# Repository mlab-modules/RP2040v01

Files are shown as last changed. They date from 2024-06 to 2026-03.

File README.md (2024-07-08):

# RP2040v01 - RP2040 Processor Module
## Introduction

The [MLAB](https://www.mlab.cz/) module RP2040v01 featuring the [RP2040](https://www.raspberrypi.com/documentation/microcontrollers/rp2040.html) processor is a powerful and flexible development board designed for a wide range of applications. The [RP2040](https://www.raspberrypi.com/documentation/microcontrollers/rp2040.html), a microcontroller from the Raspberry Pi Foundation, offers dual Arm Cortex-M0+ cores and extensive peripheral support.

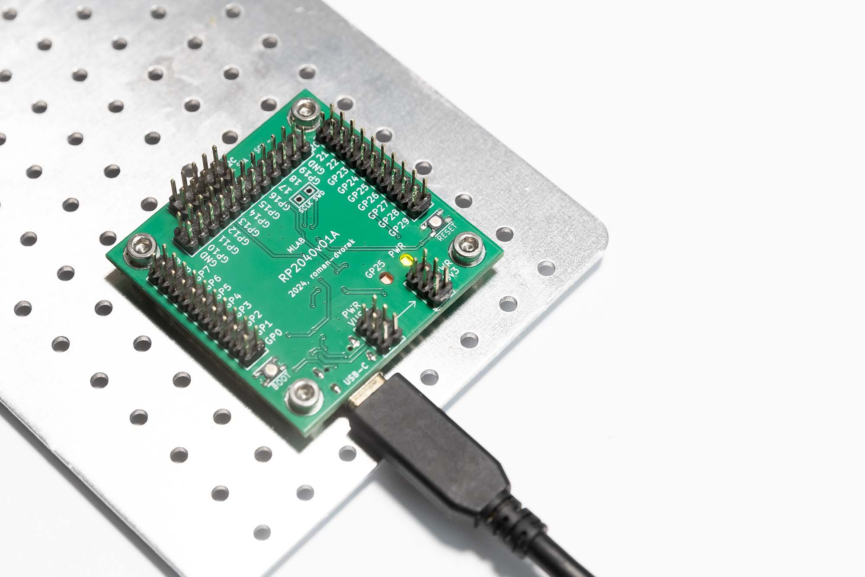
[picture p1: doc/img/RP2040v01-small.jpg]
RP2040v01 Image


## Features

- **Processor**: Dual-core Arm Cortex-M0+ [RP2040](https://www.raspberrypi.com/documentation/microcontrollers/rp2040.html).
- **Buttons**: Boot and Reset buttons for easy programming and reset.
- **GPIO**: Processor pins are exposed on doubleheader pins for flexible connectivity, as is usual in MLAB modules.
- **LED**: An LED connected via a transistor on pin 25 for status indication.
- **USB**: USB-C connector for power and data communication.
- **Power Management**: Integrated power converter to step down from 5V to 3.3V.

## Processor Details

The RP2040 processor, developed by the Raspberry Pi Foundation, is a versatile microcontroller that includes the following key features:

- **Architecture**: Dual-core Arm Cortex-M0+.
- **Clock Speed**: Up to 133 MHz.
- **Memory**: 264KB of SRAM, and support for up to 16MB of external QSPI flash memory.
- **GPIO**: 30 GPIO pins, including a rich set of I/O options like UART, SPI, I2C, PWM, and ADC.
- **Timers**: Multiple timers and a real-time clock (RTC).
- **DMA**: Direct Memory Access controller for efficient data transfer.
- **Debugging**: SWD (Serial Wire Debug) interface for debugging and development.

## Module Schematic

The schematic of the RP2040v01 module illustrates the connections and components used in the design. This includes the layout of the RP2040 processor, power management circuitry, and GPIO pin headers.



If you would like more details, please consult the example codes and used ICs documentation.

## Programming Options

The RP2040 microcontroller offers multiple programming options, providing flexibility for various types of developers:

1. **MicroPython**:
   - An easy-to-use Python interpreter ideal for beginners.
   - Allows rapid prototyping and development with an extensive set of libraries.
   - [Official documentation](https://datasheets.raspberrypi.com/pico/raspberry-pi-pico-python-sdk.pdf)

2. **C/C++ with the Pico SDK**:
   - Provides low-level access to the hardware for maximum performance.
   - Suitable for more complex projects and experienced developers.
   - Requires setting up the Pico SDK and toolchain on your development environment.
   - [User-friendly documentation](https://datasheets.raspberrypi.com/pico/raspberry-pi-pico-c-sdk.pdf)

3. **Arduino IDE**:
   - Offers a familiar environment for those used to Arduino development.
   - Supports both the Mbed OS core and the C/C++ SDK-based core.
   - Simplifies the process of writing, compiling, and uploading sketches to the RP2040.
   - [Documentation](https://github.com/earlephilhower/arduino-pico)

### Drag-and-Drop Programming:
   - Allows you to upload firmware by simply dragging and dropping a UF2 file.
   - Useful for quick updates and easy deployment without needing an IDE.
   - Minimal knowledge required, best for beginners.

## Usage

1. **Flashing Firmware**:
   - Hold the Boot button and press the Reset button.
   - Release the Reset button while holding the Boot button to enter bootloader mode.
   - Drag and drop the firmware file onto the USB drive that appears.

2. **Programming**:
   - Select the appropriate board and port and use your preferred IDE (e.g., Thonny, VS Code, Arduino IDE).
   - Write your code and upload it to the RP2040.

## References
 - [RP2040 documentation page](https://www.raspberrypi.com/documentation/microcontrollers/rp2040.html)

## Examples

Example code and projects can be found in the `examples` directory of the repository. These include basic GPIO manipulation, sensor interfacing, and communication protocols.

## Applications

### Logic analyzer
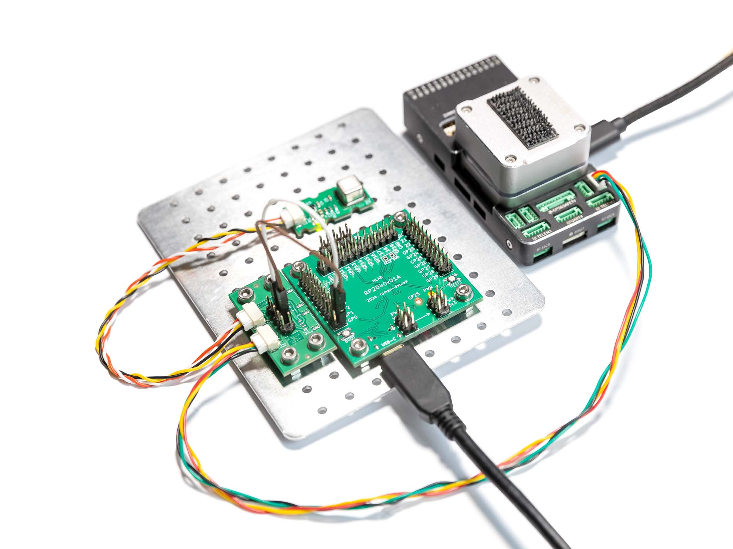
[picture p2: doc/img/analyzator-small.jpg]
RP2040-based MLAB logic analyzer


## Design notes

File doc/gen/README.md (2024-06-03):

# PCB

Board size: 50.29x50.29 mm (1.98x1.98 inches)

- This is the size of the rectangle that contains the board
- Thickness: 1.6 mm (63 mils)
- Material: FR4
- Finish: HAL
- Layers: 2
- Copper thickness: 35 µm

Solder mask: TOP / BOTTOM

- Color: Green

Silk screen: TOP / BOTTOM

- Color: White

# Important sizes

Clearance: 0.2 mm (8 mils)

Track width: 0.2 mm (8 mils)

- By design rules: 0.0 mm (0 mils)

Drill: 0.4 mm (16 mils)

- Vias: 0.4 mm (16 mils) [Design: 0.4 mm (16 mils)]
- Pads: 0.6 mm (24 mils)
- The above values are real drill sizes, they add 0.1 mm (4 mils) to plated holes (PTH)

Via: 0.6/0.3 mm (24/12 mils)

- By design rules: 0.5/0.3 mm (20/12 mils)
- Micro via: yes [0.2/0.1 mm (8/4 mils)]
- Buried/blind via: yes
- Total: 51 (thru: 51 buried/blind: 0 micro: 0)

Outer Annular Ring: 0.1 mm (4 mils)

- By design rules: 0.1 mm (4 mils)

Eurocircuits class: 8C
- Using min drill 0.35 mm for an OAR of 0.1 mm

# General stats

Components count: (SMD/THT)

- Top: 2/7 (SMD + THT)
- Bottom: 33/0 (SMD)

Defined tracks:

- 0.2 mm (8 mils)
- 0.8 mm (31 mils)

Used tracks:

- 0.2 mm (8 mils) (138) defined: yes
- 0.3 mm (12 mils) (218) defined: no
- 0.4 mm (16 mils) (41) defined: no
- 0.5 mm (20 mils) (42) defined: no

Defined vias:

Used vias:

- 0.6/0.3 mm (24/12 mils) (Count: 51, Aspect: 2.7 A) defined: no

Holes (excluding vias):

- 0.5 mm (20 mils) (32)
- 0.65 mm (26 mils) (2)
- 0.89 mm (35 mils) (88)
- 3.2 mm (126 mils) (4)

Oval holes:

- 0.6x1.4 mm (24x55 mils) (2)
- 0.6x1.7 mm (24x67 mils) (2)
- 1.9x2.4 mm (75x94 mils) (2)

Drill tools (including vias and computing adjusts and rounding):

- 0.4 mm (16 mils) (51)
- 0.6 mm (24 mils) (32)
- 0.65 mm (26 mils) (2)
- 0.7 mm (28 mils) (4)
- 1.0 mm (39 mils) (88)
- 1.9 mm (75 mils) (2)
- 3.3 mm (130 mils) (4)

Solder paste stats:

Using a paste with 87.75 % alloy, that has an specific gravity for the alloy of 7.4 g/cm³
and 1.0 g/cm³ for the flux. This paste has an specific gravity of  4.15 g/cm³.

The stencil thickness is  0.12 mm.

| Side | Pads with paste | Area [mm²] | Paste [g] |
|---|---|---|---|
| Top | 8 | 5.46 | 0.03 |
| Bottom | 149 | 133.21 | 0.66 |
| Total  | 157 | 138.67 | 0.69 |

Note: this is just an approximation to the theoretical value. Margins of the solder mask and waste aren't computed.

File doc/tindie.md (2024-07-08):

## RP2040v01 - Powerful Development Module

### What is it?

MLAB RP2040v01 is an MLAB module containing a dual-core ARM RP2040 processor. Thanks to the sophisticated design of the MLAB system and a vast array of additional modules, you can quickly and flexibly create complex devices. It is ideal for experimental, educational, scientific, and industrial applications.

### Why did you make it?

We created the RP2040v01 to provide developers with a robust and flexible platform that simplifies the process of creating and prototyping projects. As part of the MLAB ecosystem, this module can be combined with other MLAB modules to build a wide range of constructions and devices, catering to both beginners and advanced users.

### What makes it special?

- **Dual-Core Processor**: Utilizes the RP2040 microcontroller with dual Arm Cortex-M0+ cores, capable of up to 133 MHz.
- **Comprehensive Connectivity**: Features 30 GPIO pins, including UART, SPI, I2C, PWM, and ADC.
- **User-Friendly Design**: Includes Boot and Reset buttons, an LED indicator, and a USB-C connector for power and data.
- **Flexible Programming**: Supports MicroPython, C/C++, and Arduino IDE for a wide range of development needs.
- **Easy Firmware Updates**: Drag-and-drop UF2 file uploads for quick firmware updates without needing an IDE.
- **MLAB Compatibility**: Integrates seamlessly with other MLAB modules, enabling the creation of complex systems and devices.

### Features

- **Processor**: Dual-core Arm Cortex-M0+ RP2040.
- **Memory**: 264KB SRAM, support for up to 16MB external QSPI flash.
- **GPIO**: 30 pins with diverse I/O options.
- **USB**: USB-C for power and communication.
- **Buttons**: Boot and Reset.
- **LED**: Status LED on pin 25.
- **Power Management**: Integrated 5V to 3.3V converter.

### Technical Specifications

- **Clock Speed**: Up to 133 MHz.
- **Timers**: Multiple timers and RTC.
- **DMA**: Direct Memory Access controller.
- **Debugging**: SWD interface.

### Possible Uses

- Prototyping and development
- Educational projects
- IoT applications
- Sensor interfacing
- Creating complex systems and designs with other MLAB modules

# The package includes:
- RP2040v01A module with pin headers soldered.
- MLAB ALBASE mounting screw mounted in the module

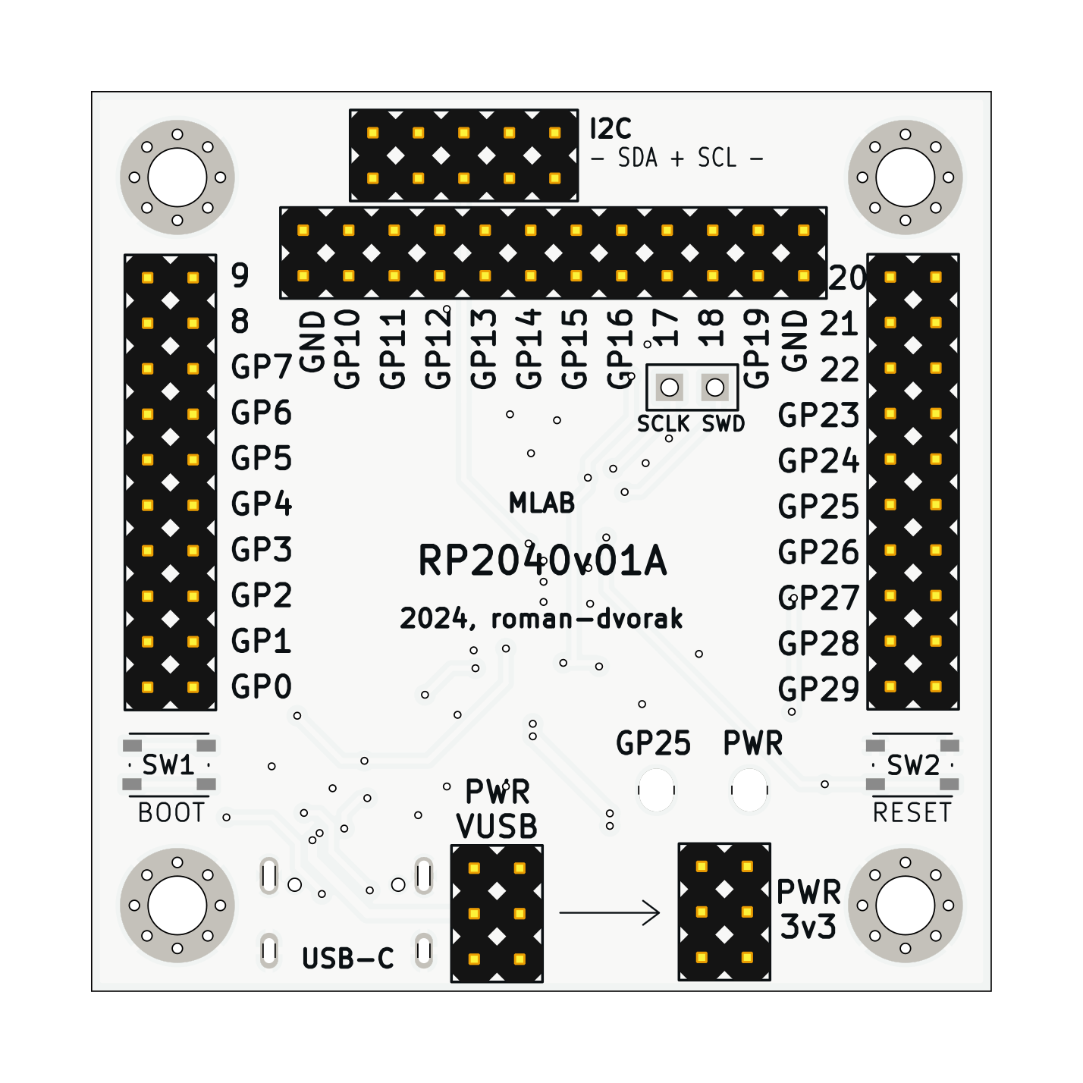
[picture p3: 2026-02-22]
doc/gen/img/RP2040v01-top.png

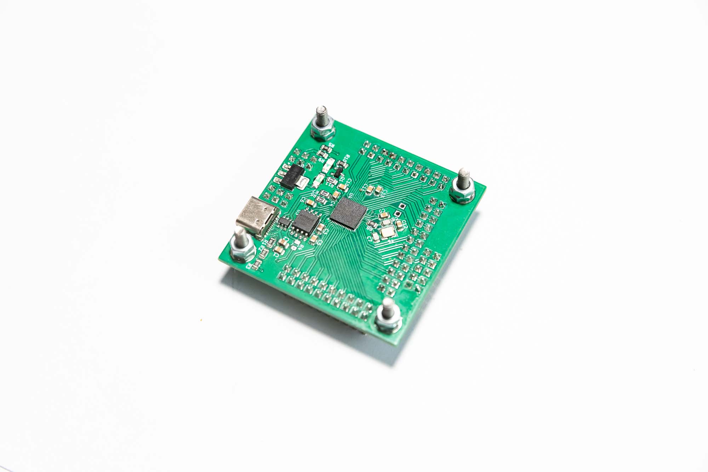
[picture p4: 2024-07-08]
doc/img/RP2040v01_b-small.jpg

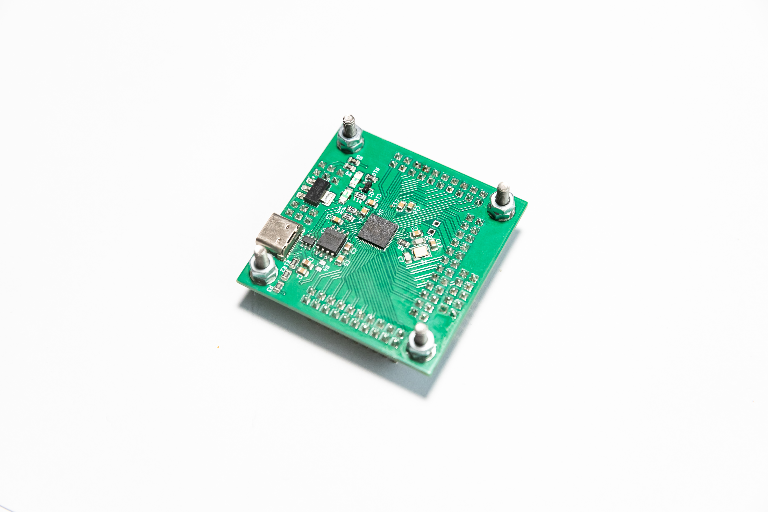
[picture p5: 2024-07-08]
doc/img/RP2040v01_b.jpg

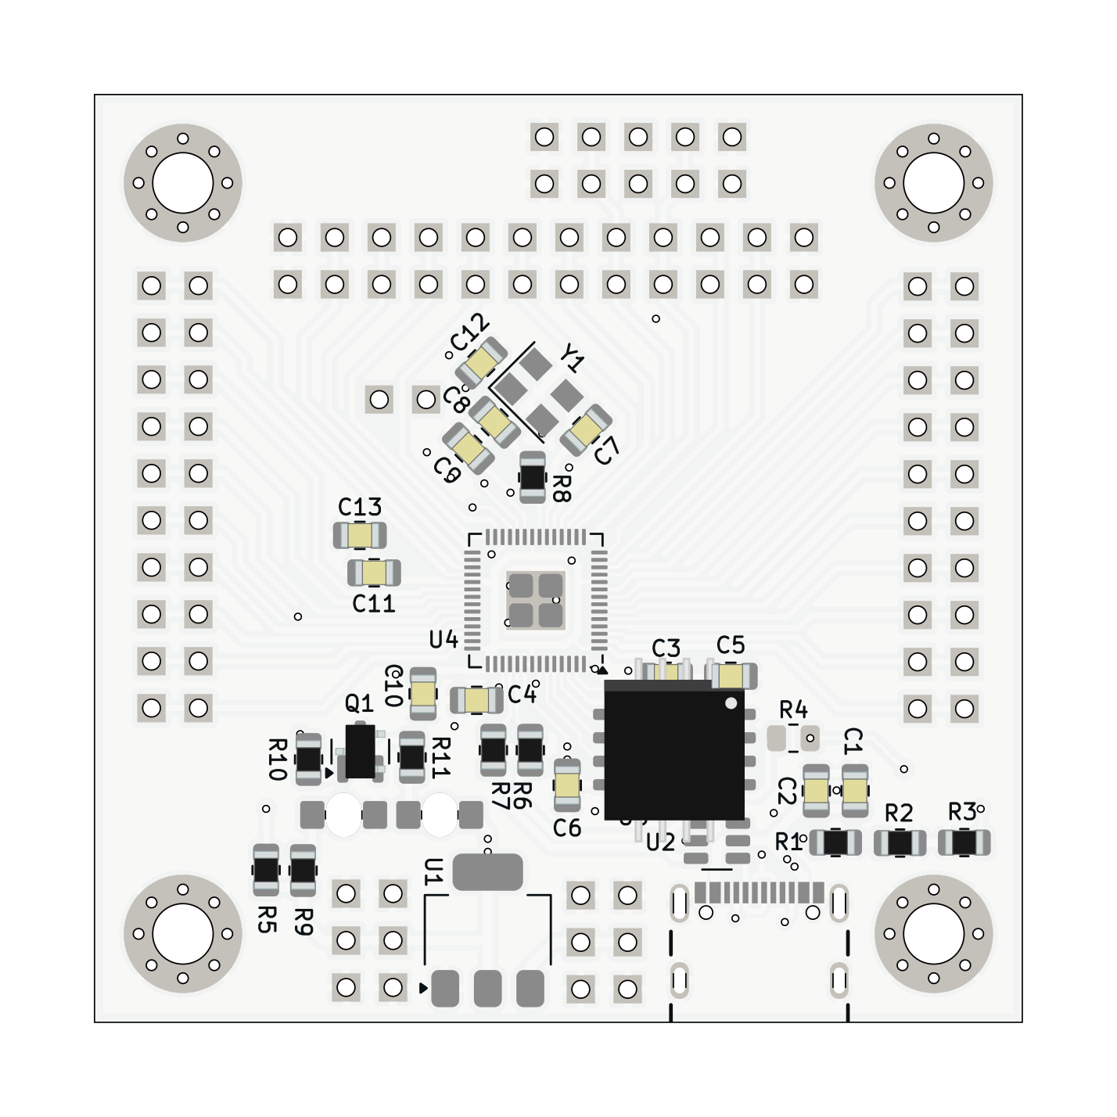
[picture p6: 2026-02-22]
doc/gen/img/RP2040v01-bottom.png

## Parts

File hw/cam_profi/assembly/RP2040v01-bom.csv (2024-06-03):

Component | Description | Part | References | Value | Footprint | Quantity Per PCB | Datasheet | obchod
1 | Unpolarized capacitor, small symbol | C_Small | C7C8 | 27p | C_0805_2012Metric | 2 | ~ | TME
2 | Unpolarized capacitor, small symbol | C_Small | C1C4C5C6C9C10C11 | 100n | C_0805_2012Metric | 7 | ~ | TME
3 | Unpolarized capacitor, small symbol | C_Small | C12C13 | 1u | C_0805_2012Metric | 2 | ~ | TME
4 | Unpolarized capacitor, small symbol | C_Small | C2C3 | 10u | C_0805_2012Metric | 2 | ~ | TME
5 | Light emitting diode, small symbol | LED_Small | D2 | Green | LED_1206_KPTR | 1 | ~ | OK
6 | Light emitting diode, small symbol | LED_Small | D1 | Red | LED_1206_KPTR | 1 | ~ | OK
7 | 2x03 2.54 mm pitch header, 2 pins next to each other are connected | HEADER_2x03_PARALLEL | J1J3 | HEADER_1x03 | Straight_2x03 | 2
8 | 2x10 2.54 mm pitch header, 2 pins next to each other are connected | HEADER_2x10_PARALLEL | J5J6 | HEADER_1x10 | Straight_2x10 | 2
9 | 2x12 2.54 mm pitch header, 2 pins next to each other are connected | HEADER_2x12_PARALLEL | J7 | HEADER_1x10 | Straight_2x12 | 1
10 | 2x05 2.54 mm pitch header, 2 pins next to each other are connected | HEADER_2x05_PARALLEL | J8 | HEADER_2x05 | Straight_2x05 | 1
11 | USB 2.0-only Type-C Receptacle connector | USBC_USB4105-GF-A | J2 | USBC_USB4105-GF-A | USBC GCT_USB4105-GF-A | 1 | https://www.usb.org/sites/default/files/documents/usb_type-c.zip | OK
12 | NPN transistor, base/collector/emitter | Q_NPN_BCE | Q1 | BC817-25 | SOT-23 | 1 | ~ | TME
13 | Resistor, small symbol | R_Small | R6R7 | 27R4 | R_0805_2012Metric | 2 | ~ | TME
14 | Resistor, small symbol | R_Small | R9R10 | 200R | R_0805_2012Metric | 2 | ~ | TME
15 | Resistor, small symbol | R_Small | R11 | 390R | R_0805_2012Metric | 1 | ~
16 | Resistor, small symbol | R_Small | R3R5R8 | 1k | R_0805_2012Metric | 3 | ~ | TME
17 | Resistor, small symbol | R_Small | R1R2 | 5k1 | R_0805_2012Metric | 2 | ~ | TME
18 | Push button switch, generic, two pins | SW_Push | SW1SW2 | 434133025816 | SW_Push_1P1T_NO_Vertical_Wuerth_434133025816 | 2 | ~ | TME
19 | 1A Low drop-out regulator, Fixed Output 3.3V, SOT-223 | NCP1117-3.3_SOT223 | U1 | NCP1117-3.3 | SOT-223-3_TabPin2 | 1 | http://www.onsemi.com/pub_link/Collateral/NCP1117-D.PDF | TME
20 | A microcontroller by Raspberry Pi | RP2040 | U4 | RP2040 | QFN-56-1EP_7x7mm_P0.4mm_EP3.2x3.2mm | 1 | https://datasheets.raspberrypi.com/rp2040/rp2040-datasheet.pdf | Farnell
21 | Very low capacitance ESD protection diode, 2 data-line, SOT-23-6 | USBLC6-2SC6 | U2 | USBLC6-2SC6 | SOT-23-6 | 1 | https://www.st.com/resource/en/datasheet/usblc6-2.pdf | TME
22 | 128Mb Serial Flash Memory, Standard/Dual/Quad SPI, SOIC-8 | W25Q128JVS | U3 | W25Q64JVSSIQ | SOIC-8_5.23x5.23mm_P1.27mm | 1 | http://www.winbond.com/resource-files/w25q128jv_dtr%20revc%2003272018%20plus.pdf | Mouser
23 | Four pin crystal, GND on pins 2 and 4 | Crystal_GND24 | Y1 | LFXTAL082069 | Crystal_SMD_SeikoEpson_FA238V-4Pin_3.2x2.5mm | 1 | ~ | Farnell

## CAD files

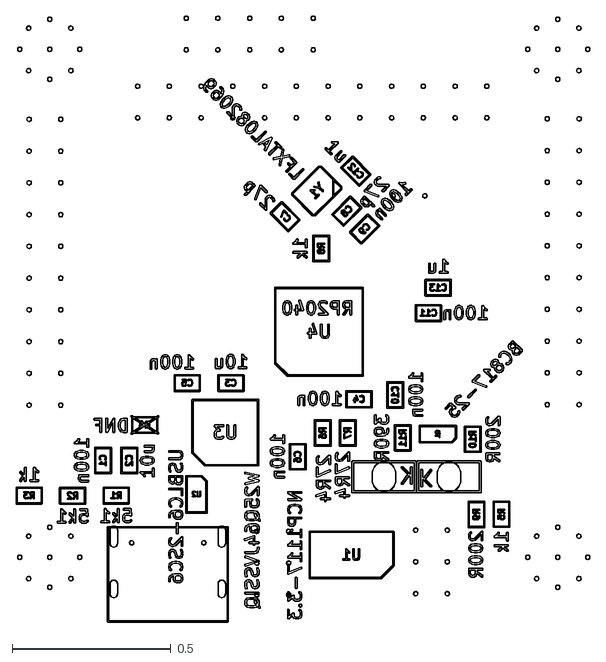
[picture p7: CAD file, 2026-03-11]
doc/gen/dxf/RP2040v01-B_Fab.dxf
1.81 x 1.91

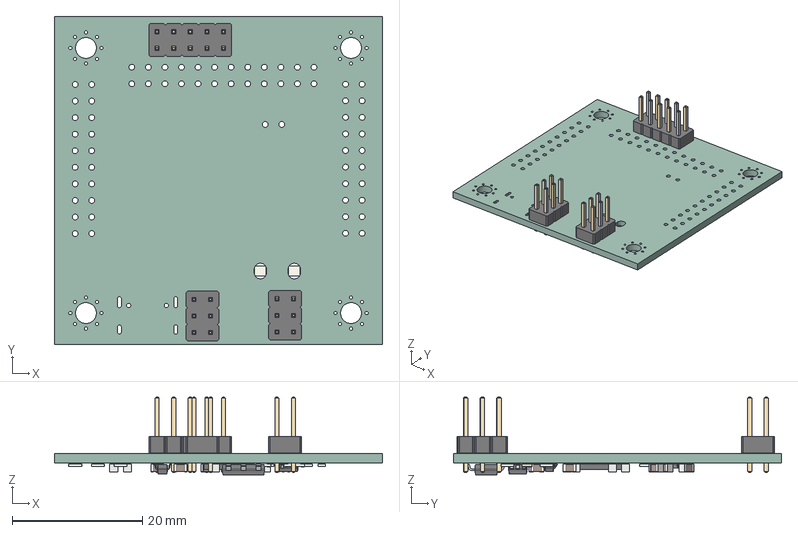
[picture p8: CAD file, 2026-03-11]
doc/gen/RP2040v01.step
50.3 x 50.3 x 11.9 mm
PinHeader_2x03_P2.54mm_Vertical x 2
PinHeader_2x05_P2.54mm_Vertical
C_0805_2012Metric x 13
SOT-223
SOT-23
QFN-56-1EP_7x7mm_P0.4mm_EP3.2x3.2mm
Crystal_SMD_SeikoEpson_FA238V-4Pin_3.2x2.5mm
R_0805_2012Metric x 10
LED_1206_3216Metric x 2
SOT-23-6
kibot_x3ycq2mz_PCB

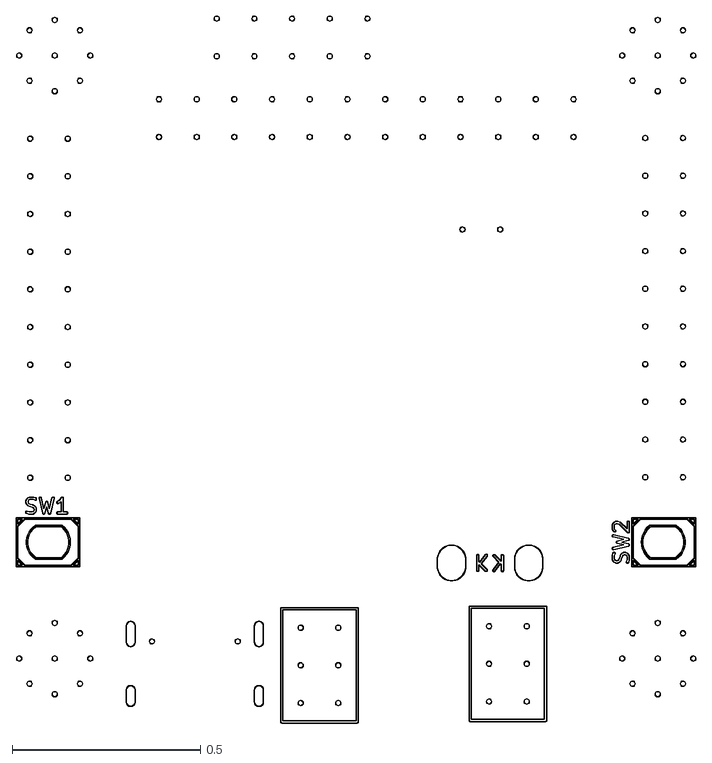
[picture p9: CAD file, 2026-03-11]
doc/gen/dxf/RP2040v01-F_Fab.dxf
1.80 x 1.88

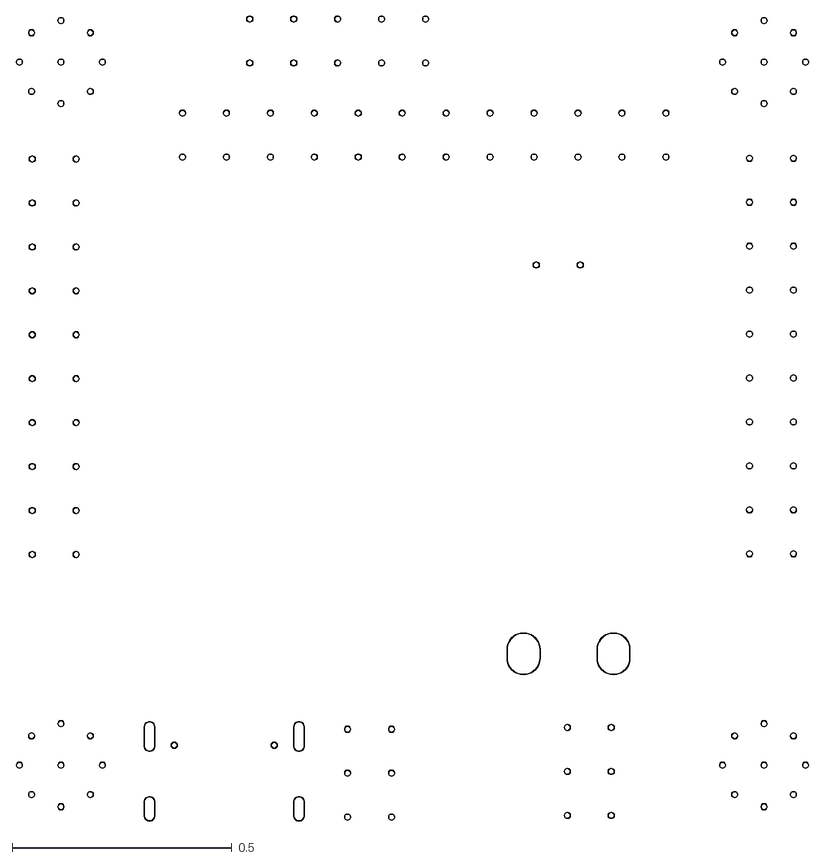
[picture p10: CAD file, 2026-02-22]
doc/gen/dxf/RP2040v01-User_3.dxf
1.80 x 1.83

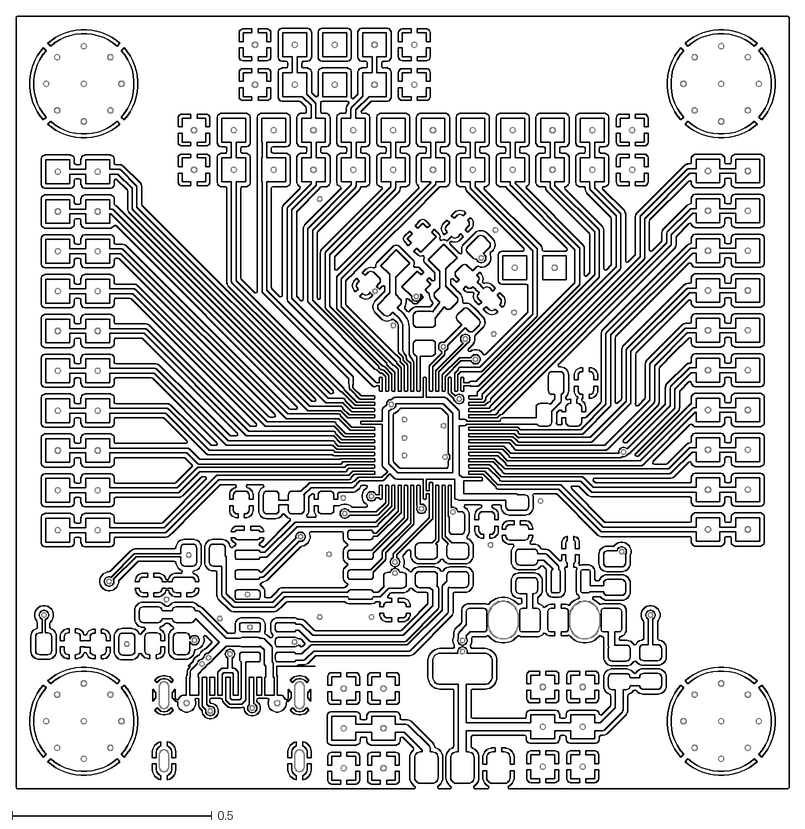
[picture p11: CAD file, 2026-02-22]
doc/gen/dxf/RP2040v01-B_Cu.dxf
1.94 x 1.94

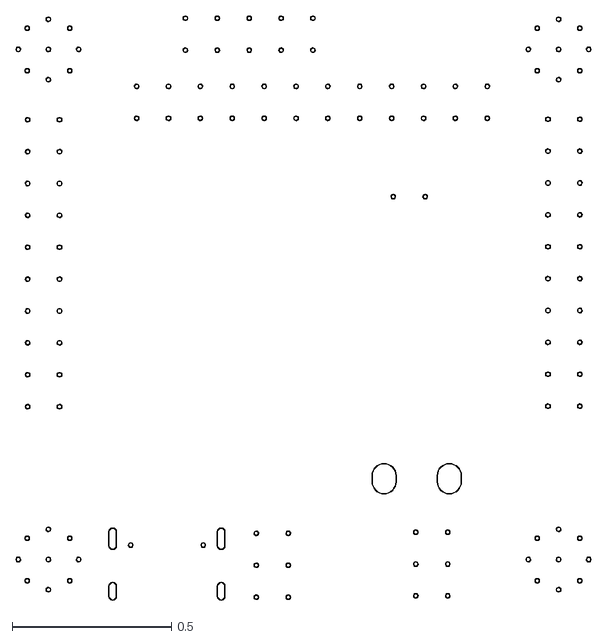
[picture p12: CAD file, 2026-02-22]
doc/gen/dxf/RP2040v01-B_Adhesive.dxf
1.80 x 1.83

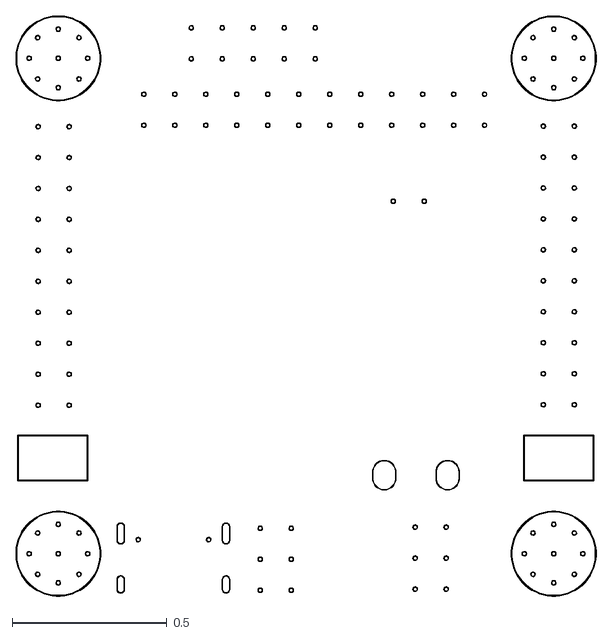
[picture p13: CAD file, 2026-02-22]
doc/gen/dxf/RP2040v01-F_Courtyard.dxf
1.87 x 1.87

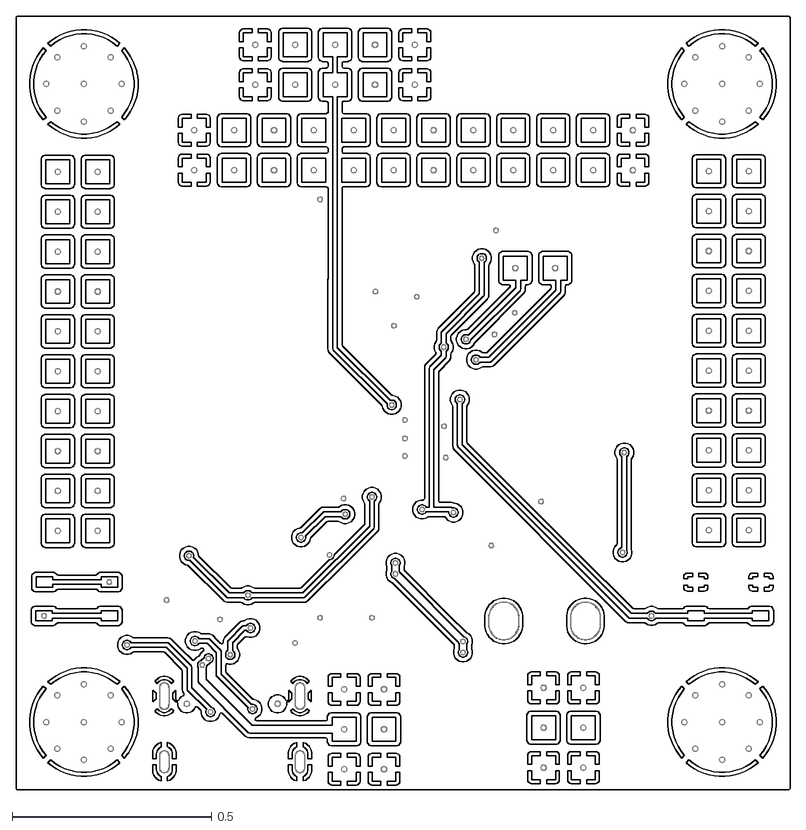
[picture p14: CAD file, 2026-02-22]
doc/gen/dxf/RP2040v01-F_Cu.dxf
1.94 x 1.94

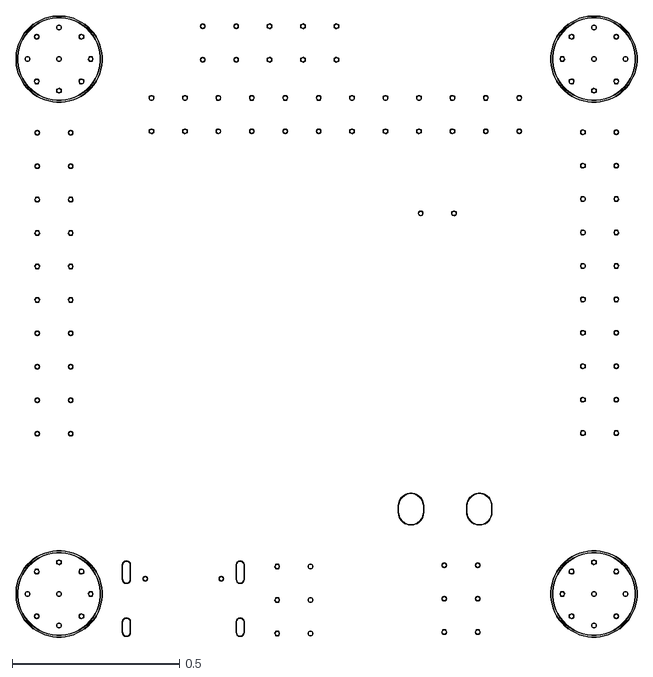
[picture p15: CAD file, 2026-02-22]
doc/gen/dxf/RP2040v01-User_Comments.dxf
1.86 x 1.86

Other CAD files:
doc/gen/dxf/RP2040v01-B_Courtyard.dxf
doc/gen/dxf/RP2040v01-B_Mask.dxf
doc/gen/dxf/RP2040v01-B_Paste.dxf
doc/gen/dxf/RP2040v01-B_Silkscreen.dxf
doc/gen/dxf/RP2040v01-Edge_Cuts.dxf
doc/gen/dxf/RP2040v01-F_Mask.dxf
doc/gen/dxf/RP2040v01-F_Paste.dxf
doc/gen/dxf/RP2040v01-F_Silkscreen.dxf

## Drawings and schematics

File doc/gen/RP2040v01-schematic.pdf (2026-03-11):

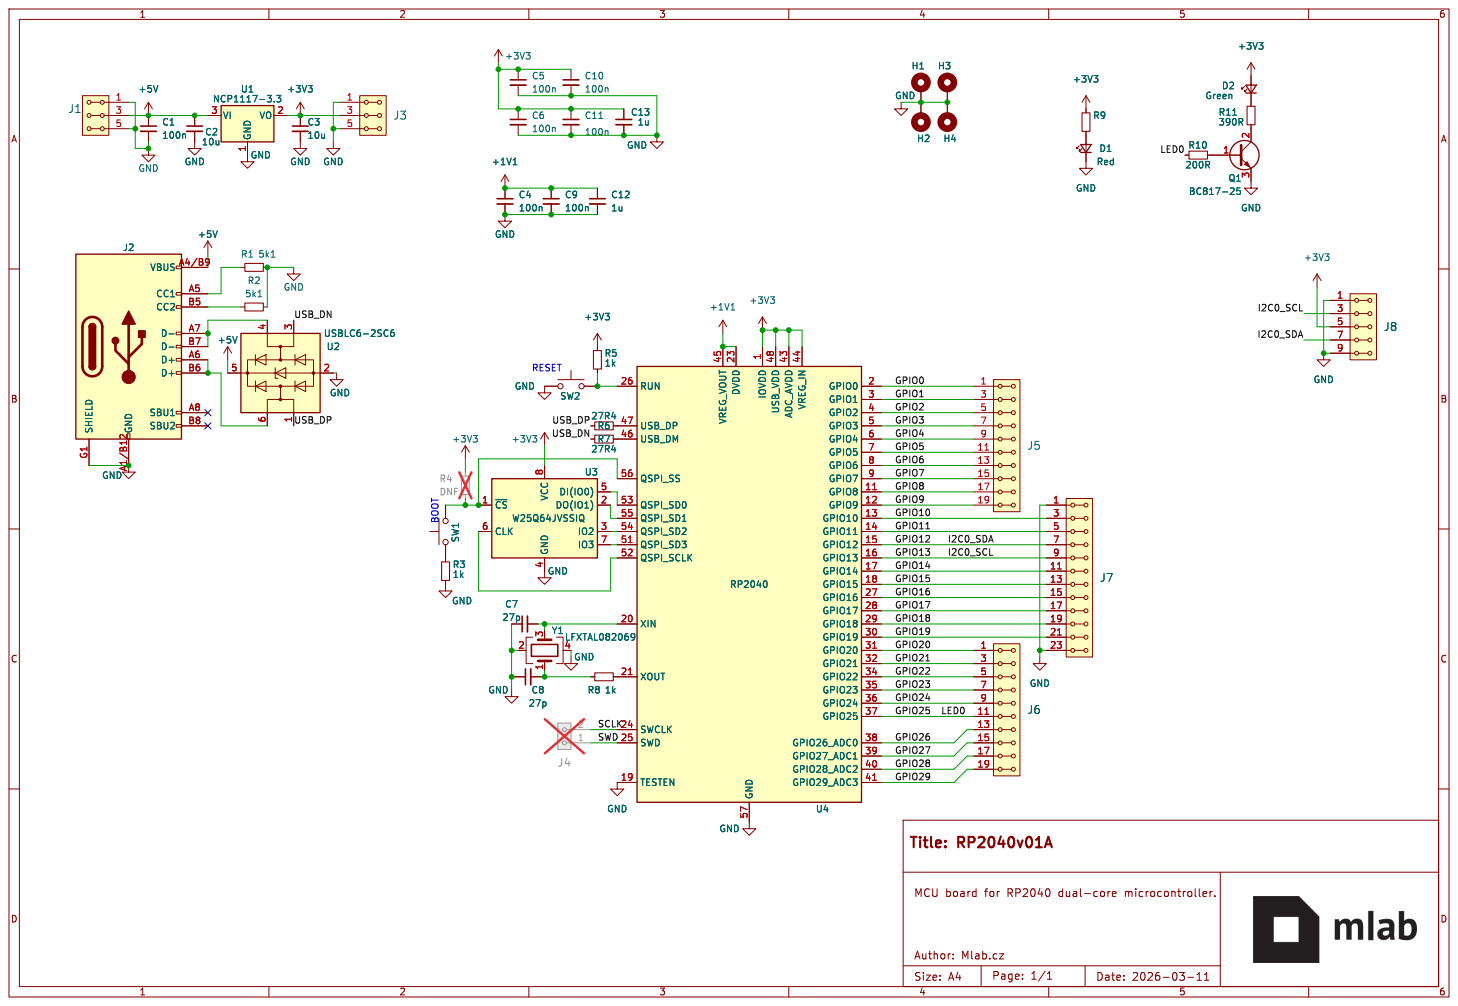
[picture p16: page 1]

3 U2 USBLC6-2SC6 +5V GND SHIELD G1 GND A1/B12 VBUS A4/B9 CC1 A5 CC2 B5 D- A7 D- B7 D+ A6 D+ B6 SBU1 A8 SBU2 B8

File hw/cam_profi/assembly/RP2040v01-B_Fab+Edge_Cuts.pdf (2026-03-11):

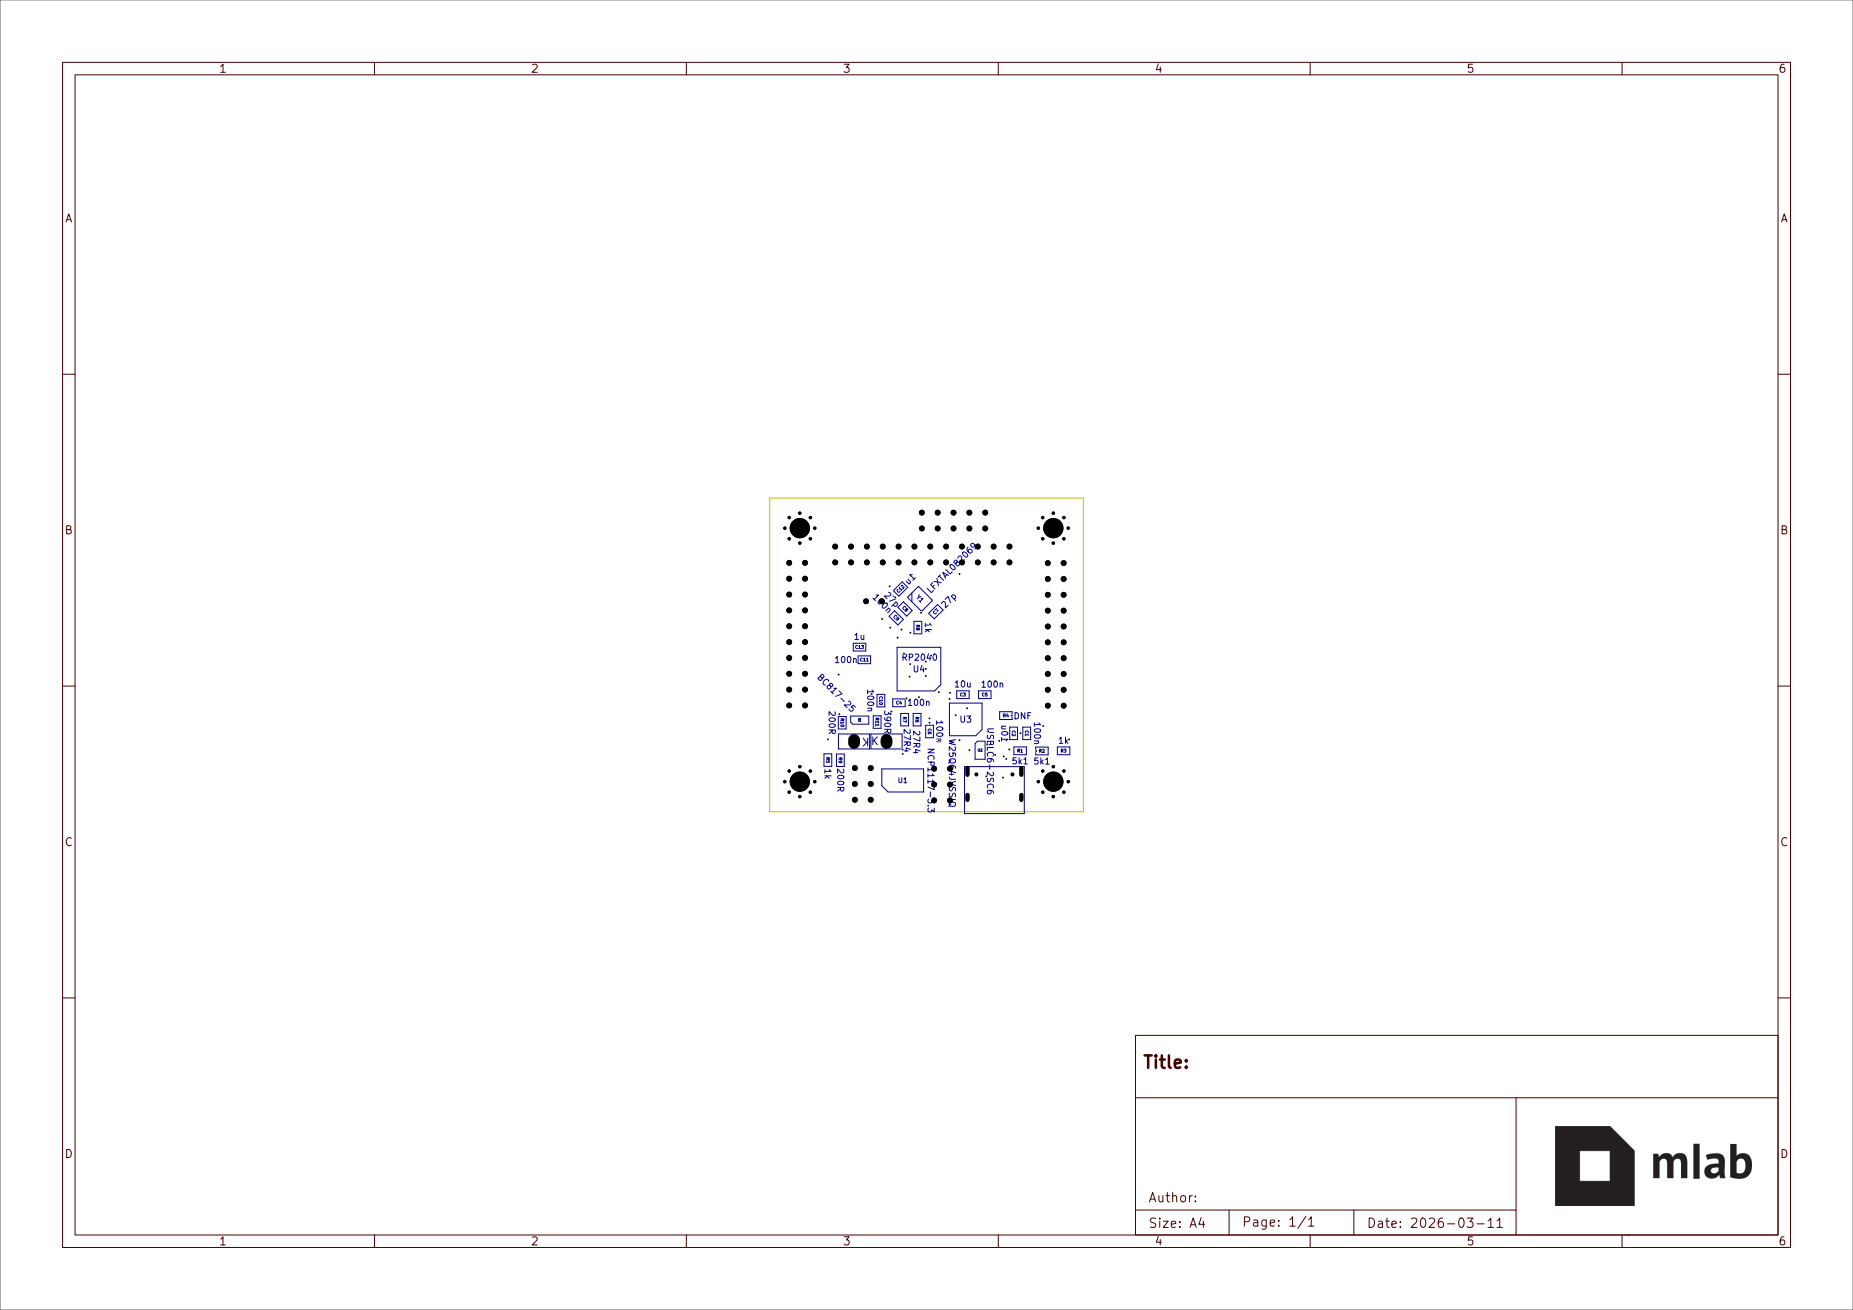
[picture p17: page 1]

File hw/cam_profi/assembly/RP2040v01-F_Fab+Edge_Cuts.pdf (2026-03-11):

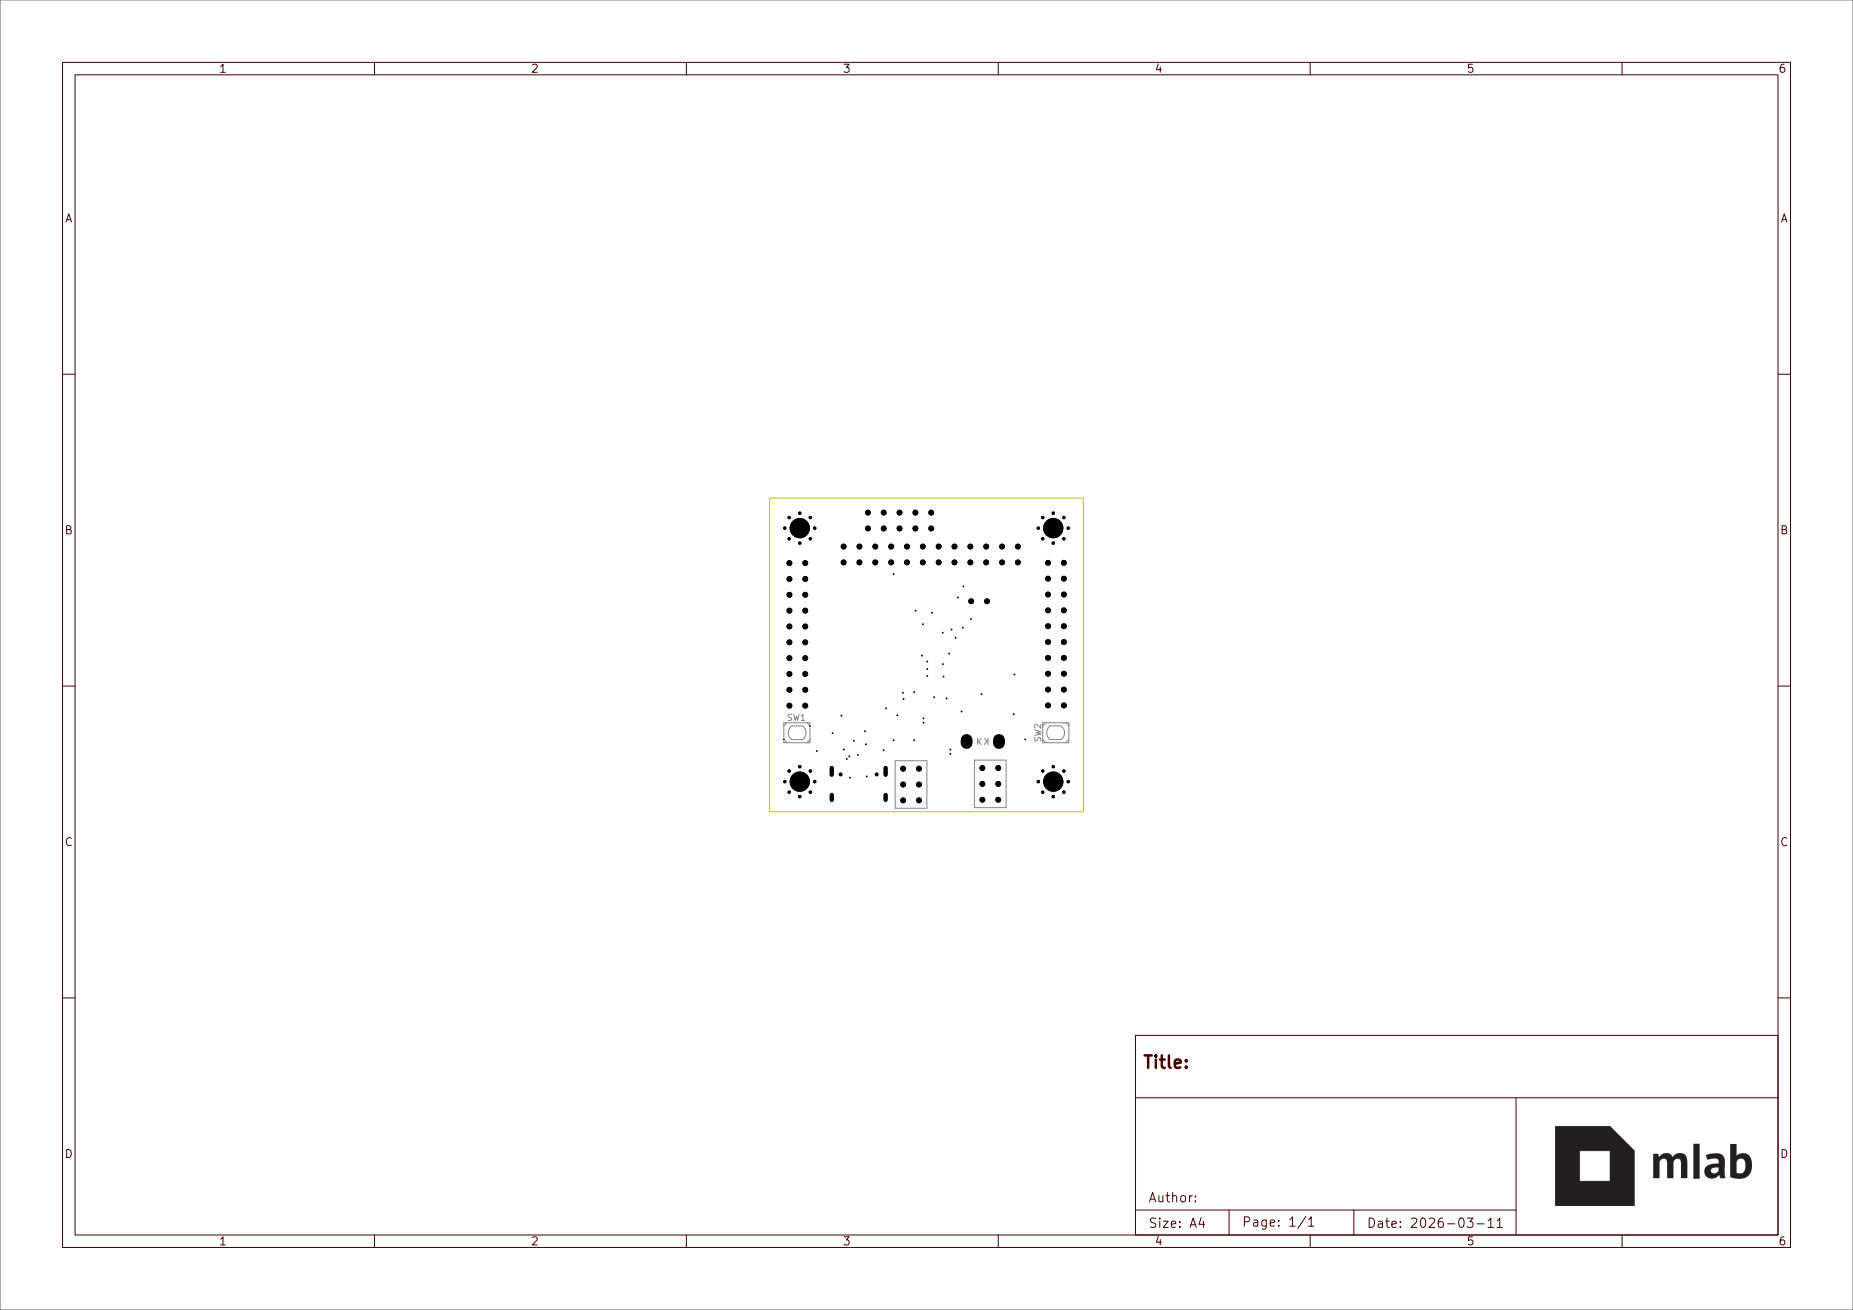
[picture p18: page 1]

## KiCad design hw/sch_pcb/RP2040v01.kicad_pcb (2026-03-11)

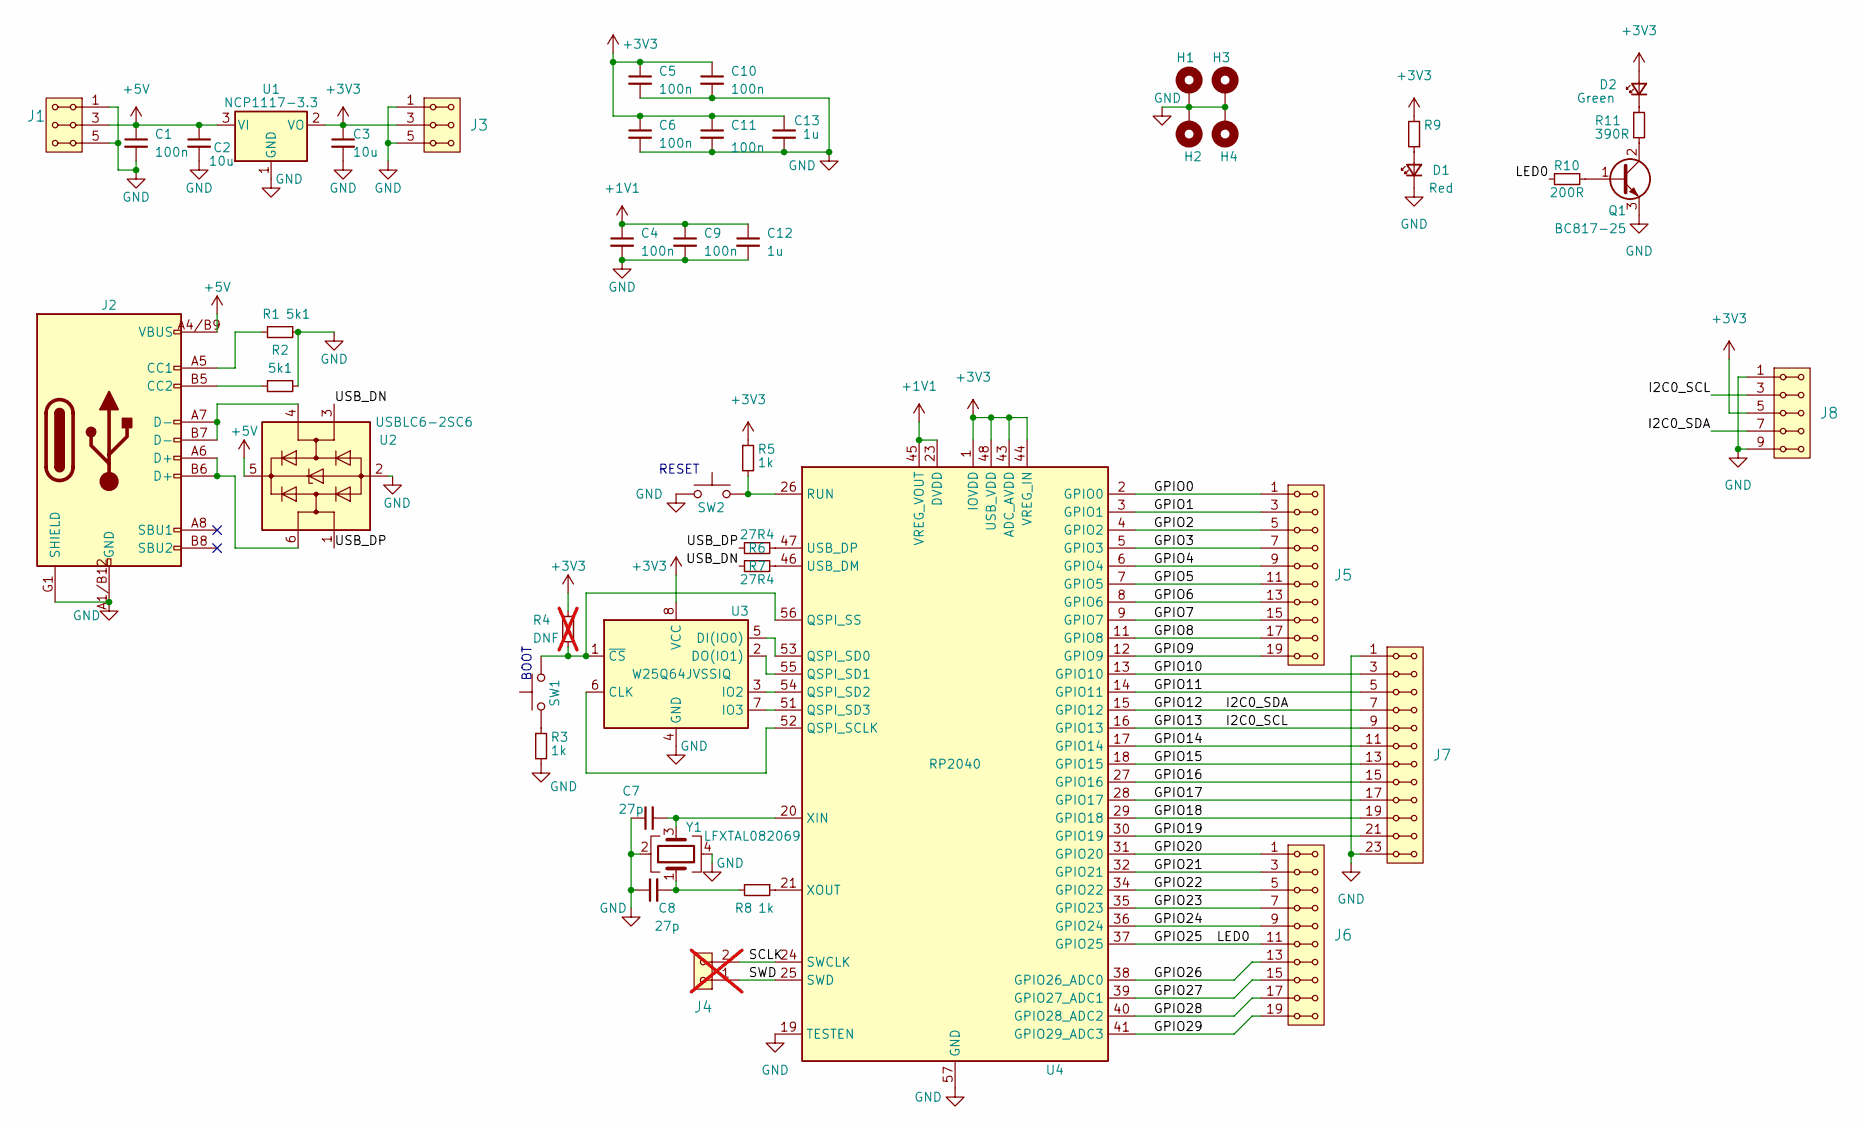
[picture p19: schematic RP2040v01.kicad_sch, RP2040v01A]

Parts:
C1, C4, C5, C6, C9, C10, C11: 100n; C_0805_2012Metric
C2, C3: 10u; C_0805_2012Metric
C7, C8: 27p; C_0805_2012Metric
C12, C13: 1u; C_0805_2012Metric
D1: Red; LED_1206_KPTR
D2: Green; LED_1206_KPTR
H1, H2, H3, H4: MountingHole_Pad; MountingHole_3.2mm_M3_Pad_Via
J1, J3: HEADER_1x03; Straight_2x03
J2: USBC_USB4105-GF-A; USBC GCT_USB4105-GF-A
J4: HEADER_1x10; Straight_1x02; not fitted
J5, J6: HEADER_1x10; Straight_2x10
J7: HEADER_1x10; Straight_2x12
J8: HEADER_2x05; Straight_2x05
Q1: BC817-25; SOT-23
R1, R2: 5k1; R_0805_2012Metric
R3, R5, R8: 1k; R_0805_2012Metric
R4: DNF; R_0805_2012Metric; not fitted
R6, R7: 27R4; R_0805_2012Metric
R9, R10: 200R; R_0805_2012Metric
R11: 390R; R_0805_2012Metric
SW1, SW2: 434133025816; SW_Push_1P1T_NO_Vertical_Wuerth_434133025816
U1: NCP1117-3.3; SOT-223-3_TabPin2
U2: USBLC6-2SC6; SOT-23-6
U3: W25Q64JVSSIQ; SOIC-8_5.23x5.23mm_P1.27mm
U4: RP2040; QFN-56-1EP_7x7mm_P0.4mm_EP3.2x3.2mm
Y1: LFXTAL082069; Crystal_SMD_SeikoEpson_FA238V-4Pin_3.2x2.5mm

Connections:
+1V1: C4.1, C9.1, C12.1, U4.23 (DVDD), U4.45 (VREG_VOUT), U4.50 (DVDD)
+3V3: C3.1, C5.1, C6.1, C10.1, C11.1, C13.1, D2.2 (A), J3.3, J3.4, J8.5, J8.6, R4.1, R5.1, R9.2, U1.2 (VO), U3.8 (VCC), U4.1 (IOVDD), U4.10 (IOVDD), U4.22 (IOVDD), U4.33 (IOVDD), U4.42 (IOVDD), U4.43 (ADC_AVDD), U4.44 (VREG_IN), U4.48 (USB_VDD), U4.49 (IOVDD)
+5V: C1.1, C2.1, J1.3, J1.4, J2.A4/B9 (VBUS), J2.B4/A9 (VBUS), U1.3 (VI), U2.5 (VBUS)
/GPIO0: J5.1, J5.2, U4.2 (GPIO0)
/GPIO1: J5.3, J5.4, U4.3 (GPIO1)
/GPIO2: J5.5, J5.6, U4.4 (GPIO2)
/GPIO3: J5.7, J5.8, U4.5 (GPIO3)
/GPIO4: J5.9, J5.10, U4.6 (GPIO4)
/GPIO5: J5.11, J5.12, U4.7 (GPIO5)
/GPIO6: J5.13, J5.14, U4.8 (GPIO6)
/GPIO7: J5.15, J5.16, U4.9 (GPIO7)
/GPIO8: J5.17, J5.18, U4.11 (GPIO8)
/GPIO9: J5.19, J5.20, U4.12 (GPIO9)
/GPIO10: J7.3, J7.4, U4.13 (GPIO10)
/GPIO11: J7.5, J7.6, U4.14 (GPIO11)
/GPIO12: J7.7, J7.8, J8.7, J8.8, U4.15 (GPIO12)
/GPIO13: J7.9, J7.10, J8.3, J8.4, U4.16 (GPIO13)
/GPIO14: J7.11, J7.12, U4.17 (GPIO14)
/GPIO15: J7.13, J7.14, U4.18 (GPIO15)
/GPIO16: J7.15, J7.16, U4.27 (GPIO16)
/GPIO17: J7.17, J7.18, U4.28 (GPIO17)
/GPIO18: J7.19, J7.20, U4.29 (GPIO18)
/GPIO19: J7.21, J7.22, U4.30 (GPIO19)
/GPIO20: J6.1, J6.2, U4.31 (GPIO20)
/GPIO21: J6.3, J6.4, U4.32 (GPIO21)
/GPIO22: J6.5, J6.6, U4.34 (GPIO22)
/GPIO23: J6.7, J6.8, U4.35 (GPIO23)
/GPIO24: J6.9, J6.10, U4.36 (GPIO24)
/GPIO25: J6.11, J6.12, R10.1, U4.37 (GPIO25)
/GPIO26: J6.13, J6.14, U4.38 (GPIO26_ADC0)
/GPIO27: J6.15, J6.16, U4.39 (GPIO27_ADC1)
/GPIO28: J6.17, J6.18, U4.40 (GPIO28_ADC2)
/GPIO29: J6.19, J6.20, U4.41 (GPIO29_ADC3)
/SCLK: J4.2, U4.24 (SWCLK)
/SWD: J4.1, U4.25 (SWD)
/USB_DN: R7.1, U2.3 (I/O2)
/USB_DP: R6.1, U2.1 (I/O1)
GND: C1.2, C2.2, C3.2, C4.2, C5.2, C6.2, C7.1, C8.1, C9.2, C10.2, C11.2, C12.2, C13.2, D1.1 (K), H1.1, H2.1, H3.1, H4.1, J1.1, J1.2, J1.5, J1.6, J2.A1/B12 (GND), J2.B1/A12 (GND), J2.G1 (SHIELD), J2.G2 (SHIELD), J2.G3 (SHIELD), J2.G4 (SHIELD), J3.1, J3.2, J3.5, J3.6, J7.1, J7.2, J7.23, J7.24, J8.1, J8.2, J8.9, J8.10, Q1.3 (E), R1.2, R2.2, R3.2, SW2.1, U1.1 (GND), U2.2 (GND), U3.4 (GND), U4.19 (TESTEN), U4.57 (GND), Y1.2, Y1.4
unnamed: C8.2, R8.2, Y1.1
unnamed: D1.2 (A), R9.1
unnamed: D2.1 (K), R11.1
unnamed: J2.A5 (CC1), R1.1
unnamed: J2.B5 (CC2), R2.1
unnamed: J2.A6 (D+), J2.B6 (D+), U2.6 (I/O1)
unnamed: J2.A7 (D-), J2.B7 (D-), U2.4 (I/O2)
unnamed: Q1.1 (B), R10.2
unnamed: Q1.2 (C), R11.2
unnamed: R3.1, SW1.1
unnamed: U3.6 (CLK), U4.52 (QSPI_SCLK)
unnamed: U3.5 (DI(IO0)), U4.53 (QSPI_SD0)
unnamed: U3.2 (DO(IO1)), U4.55 (QSPI_SD1)
unnamed: U3.3 (IO2), U4.54 (QSPI_SD2)
unnamed: U3.7 (IO3), U4.51 (QSPI_SD3)
unnamed: R4.2, SW1.2, U3.1 (~CS), U4.56 (QSPI_SS)
unnamed: R5.2, SW2.2, U4.26 (RUN)
unnamed: R7.2, U4.46 (USB_DM)
unnamed: R6.2, U4.47 (USB_DP)
unnamed: C7.2, U4.20 (XIN), Y1.3
unnamed: R8.1, U4.21 (XOUT)

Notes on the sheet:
BOOT
RESET

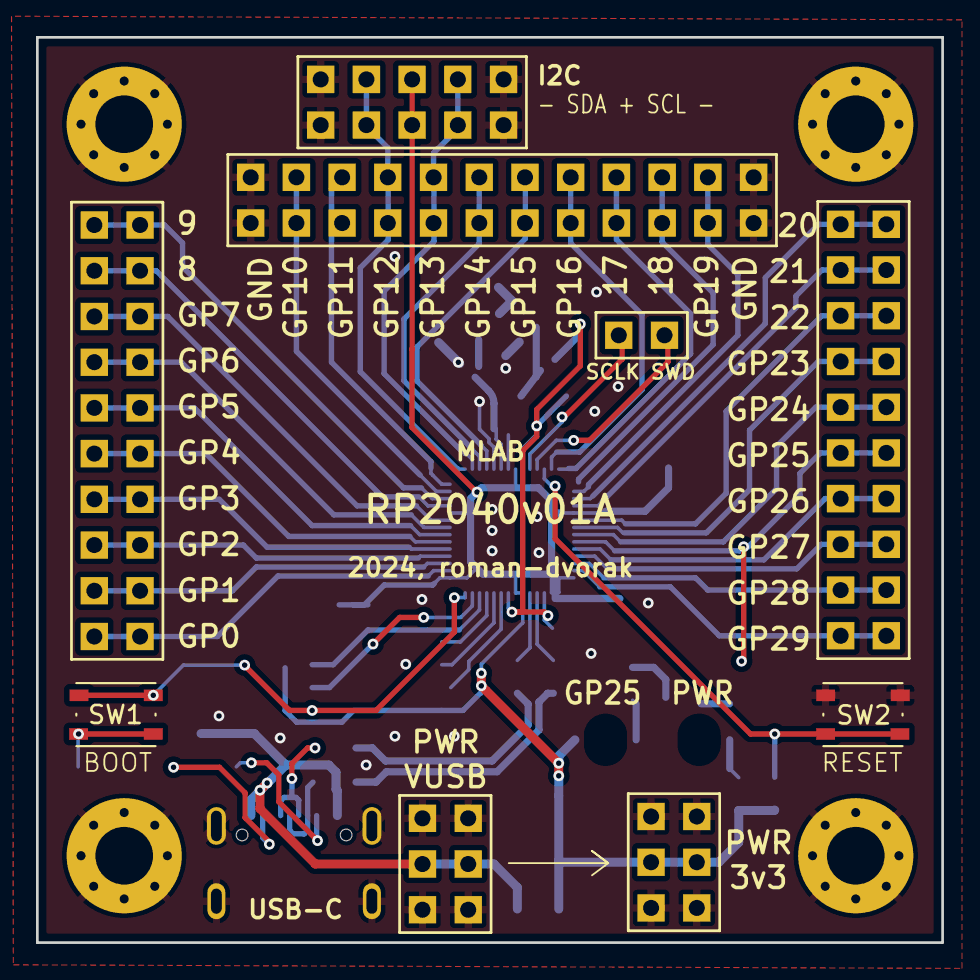
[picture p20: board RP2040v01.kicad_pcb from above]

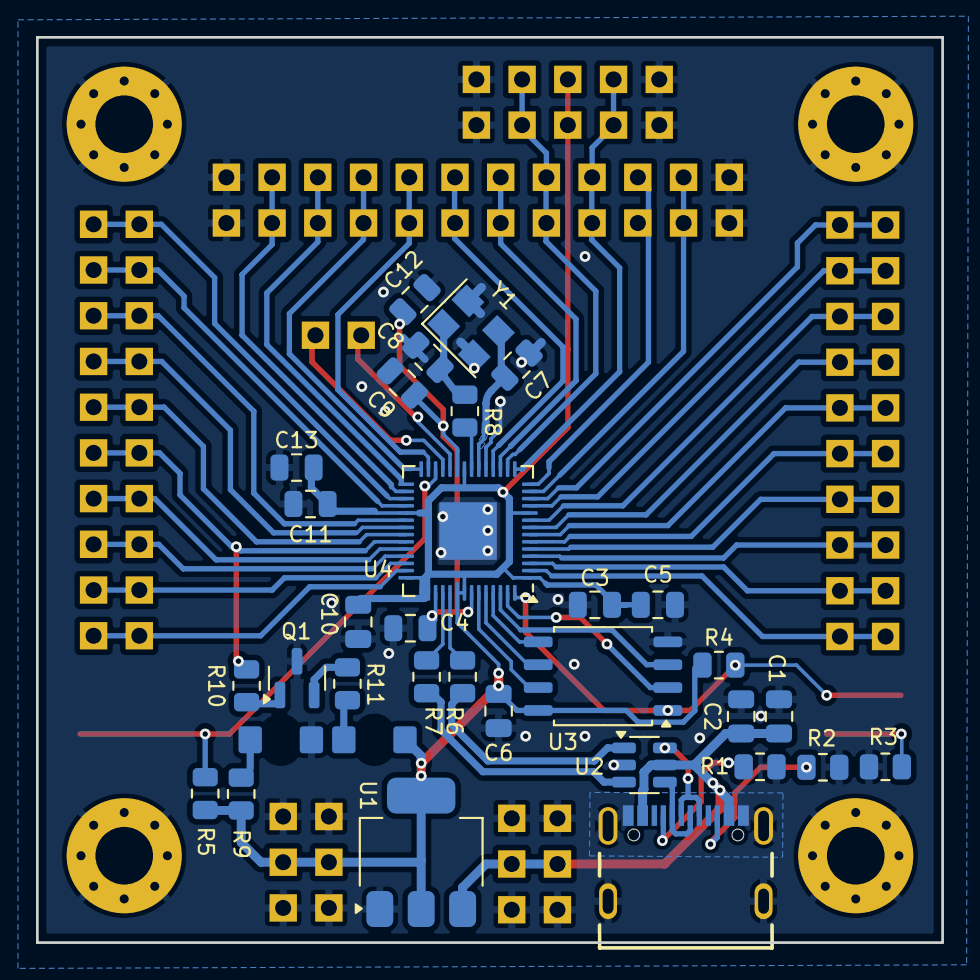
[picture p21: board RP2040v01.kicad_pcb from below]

Board: 2 copper layers, 50.3 x 50.3 mm, 46 parts (33 on the bottom side), 59 nets.

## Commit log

2024-06-03 add actions
    [RP2040V01.kicad_pcb, RP2040V01.kicad_sch]
2024-06-03 rename files
    [RP2040v01.kicad_pcb, RP2040v01.kicad_sch]
2024-06-03 Update actions products
    [RP2040v01-B_Adhesive.dxf, RP2040v01-B_Courtyard.dxf, RP2040v01-B_Cu.dxf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]
2024-06-06 Change path to title block.
    [RP2040v01.kicad_pcb, RP2040v01.kicad_sch]
2024-06-09 Fix bottom silkscreen.
    [RP2040v01.kicad_pcb]
2026-02-22 Update project to KiCADv9.
    [RP2040v01.kicad_pcb, RP2040v01.kicad_sch]
2026-02-22 Automatic update of KiCAD outputs
    [RP2040v01-B_Adhesive.dxf, RP2040v01-B_Courtyard.dxf, RP2040v01-B_Cu.dxf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]
2026-03-11 Cleanup Fab layer.
    [RP2040v01.kicad_pcb, RP2040v01.kicad_sch]
